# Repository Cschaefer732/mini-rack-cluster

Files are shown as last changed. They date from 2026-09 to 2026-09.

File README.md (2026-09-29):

# mini-rack-cluster

A 10-inch mini rack that consolidates a 3-node home fleet — dev workstation
with dual GPUs, an AI inference server, and a general-purpose server host —
plus its network gear, into one enclosure.

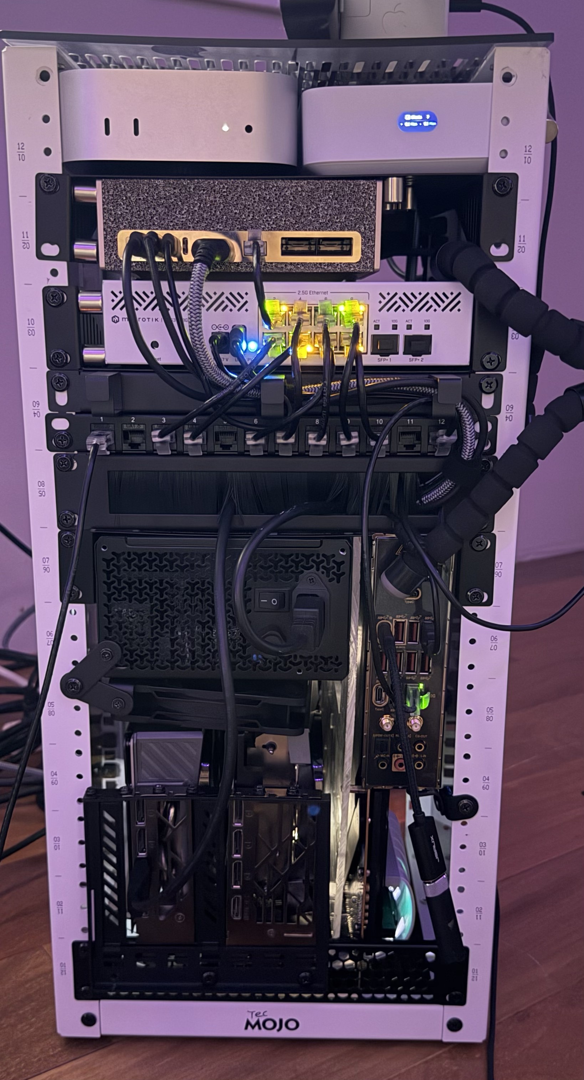
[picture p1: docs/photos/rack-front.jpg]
The rack, front view — Mac mini and UX7 gateway on top, riser card and MikroTik switch, patch panel and cable brush, PSU and vertically-mounted GPU/motherboard below


## Fleet

| Node | Role | Hardware |
|---|---|---|
| **nova-linux** | Dev workstation + GPU compute | MSI MEG X670E ACE (vertical-mounted on a hand-cut acrylic plate), Ryzen 9 9950X, RTX 5080 + RTX 4070 Ti, 32GB DDR5-4800, WD_BLACK SN850X 4TB + SN770 2TB NVMe |
| **machub** | General server host | Mac mini M4 (base, 16GB/256GB) — Vault, Postgres, IB/TWS, game streaming |
| **spark-a81e** | AI inference node | NVIDIA DGX Spark, GB10 Grace-Blackwell, 128GB unified memory — ollama model serving |
| — | Switch | MikroTik CRS310-8G+2S+ |
| — | Gateway/router | UniFi UX7 (UDMA69B) |

Each node kept its existing role from the wider fleet (see
[`personal-pc-config`](https://github.com/Cschaefer732/personal-pc-config) for full
per-machine config) — this project is the physical consolidation into one rack, not a
new cluster software stack.

## Build notes

- The MSI X670E ACE doesn't fit a standard 10" rack shelf full-size, so the board was
  pulled from its original case and mounted vertically on a cut acrylic open-frame
  plate to fit the rack footprint.
- PCIe 5.0 riser cables carry both GPUs off-board to clear rack depth (RGEEK x16
  double-reverse riser for one card, TRYX vertical-mount riser for the other).
- Cooling: ARCTIC Liquid Freezer III Pro 360 AIO on the 9950X, OwlTree PWM fan hub for
  case/rack fans.
- Power: Corsair RM850e (850W, fully modular) for the compute node.
- Cable management: Tecmojo 12-port Cat6 patch panel, GeeekPi horizontal cable manager,
  Tecmojo brush cable-entry panel, Cat6a patch cables throughout.
- Enclosure: Tecmojo 12U 10" network rack, 10.23" deep.

## Parts list + pricing

Two columns: what was actually paid (or, for parts reused from the prior nova-linux
build, the original MSRP — no receipt on hand), vs. current market price as of
2026-09-26.

| Component | Price Paid / Original | Market Price Now |
|---|---|---|
| NVIDIA DGX Spark (GB10, 128GB unified) | $4,800 | $4,699 (NVIDIA FE) — OEM partner street price ranges $4,100–$7,900 |
| MSI GeForce RTX 5080 Gaming Trio | $1,400 | ~$1,199–$1,800 (avg ~$1,580) |
| Apple Mac mini M4 (16GB/256GB) | $500 | ~$700–$1,050 — discontinued May 2026, resale now above launch price |
| MSI MEG X670E ACE motherboard | $699.99 (MSRP, reused part — no receipt) | $799.99 |
| AMD Ryzen 9 9950X | $649 (MSRP, reused part) | ~$499.99 |
| MSI GeForce RTX 4070 Ti Gaming Trio | ~$874 (MSRP, reused part) | ~$809.99 |
| WD_BLACK SN850X 4TB NVMe | $699 (MSRP, reused part) | ~$639.99 (volatile, seen $270–$640) |
| WD_BLACK SN770 2TB NVMe | $269.99 (MSRP, reused part) | ~$400 (NAND shortage) |
| Crucial 32GB DDR5-4800 (CT32G48C40U5) | ~$110 (est., no clean launch record) | ~$268–$538 (DRAM shortage) |
| MikroTik CRS310-8G+2S+ switch | $208.80 | $208.80 |
| UniFi UX7 gateway | $234 | $199 |
| Tecmojo 12U 10" rack enclosure | $139.90 | $139.90 |
| Corsair RM850e 850W PSU | $115.99 | $115.99 |
| TRYX PCIe 5.0 vertical riser | ~$74.99 | $74.99 |
| ARCTIC Liquid Freezer III Pro 360 AIO | ~$74.99 | $69.89 |
| RGEEK PCIe 5.0 x16 double-reverse riser | $39.99 | $39.99 |
| DIY acrylic open-frame case (cut for vertical mobo mount) | $29.89 | $29.89 |
| Tecmojo 12-port Cat6 patch panel | $15.99 | $15.99 |
| Tecmojo brush cable-entry panel | $14.69 | $14.69 |
| OwlTree 4-pin PWM fan controller | $16.99 | $16.99 |
| GeeekPi 10" horizontal cable manager | $11.19 | $11.19 |
| Cat6a patch cables (10-pack) | $10.99 | $10.99 |
| **Total** | **~$10,990** | **~$11,519** |

Build cost went *up* since assembly — the 2026 AI-driven GPU/NAND/DRAM shortage
outpaced normal depreciation on every reused part.

## Repo layout

```
docs/           build write-ups, LinkedIn post draft, photos
configs/        network device summaries (port maps, gateway notes — no raw exports)
cad/            slide-out mobo/GPU/PSU tray: tray-v1/ (current, from asset-forge/3d-design) + OpenSCAD v0.1-0.6 history
scripts/        automation — TODO, none written yet
wiki/           Obsidian-compatible knowledge layer for this project
```

## Status

- [x] Physical build complete
- [x] Parts + pricing documented
- [x] Build photos added (`docs/photos/`)
- [ ] Slide-out mobo/GPU/PSU tray — v1.0 rebuilt from zero in `cad/tray-v1/` (edge-on board, 10-inch 8U faceplate, 280 audit checks pass, 9 sabotage mutants caught); needs a measured rack opening, slide hardware, and a dry fit before printing
- [ ] Rack elevation / wiring diagram
- [ ] `scripts/` — no automation defined yet

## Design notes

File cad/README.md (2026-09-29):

> **SUPERSEDED 2026-09-29.** Everything below is the OpenSCAD v0.1-0.6 history. Those versions
> modelled the motherboard as a plate facing the front; it stands edge-on with its IO edge to the
> front (measured from the build photo). The current design is [`tray-v1/`](tray-v1/README.md),
> built and audited from [`asset-forge/3d-design`](https://github.com/Cschaefer732/asset-forge/tree/main/3d-design).
> Also wrong in the files below: the EIA-310 hole pattern, the board dimensions (304.8 mm is the
> IO edge), and the ATX hole table.

# CAD — mobo/GPU/PSU slide-out tray

`mobo-gpu-psu-tray.scad` — parametric OpenSCAD model. Every dimension that
matters is a named variable at the top of the file with a comment saying
whether it's a sourced spec or a placeholder you need to verify.

**Status: v0.6 draft, not print-ready, and now honestly blocked on one
real measurement.** Manifold STLs export clean (`NoError` on the combined
model and all per-part exports). Every panel's cutout is now checked to
actually fit inside the panel it's cut from. But the floorplan this
round surfaced a real physical conflict: **the PSU and IO shield, sized
to what they actually need, require ~341mm side by side — the rack is
only ~270-280mm.** See "v0.6" below before printing anything.

## v0.6 — floorplan rebuilt from real sizes, found a real width conflict

v0.5 shipped with two more defects, on top of the ones it claimed to
fix:

- **The IO rotation in v0.5 was wrong.** It was based on the photo
  showing ports "stacked vertically" and concluding the whole board was
  mounted rotated 90&deg;. Cropped and zoomed into the actual photo this
  round: that's just the MSI X670E ACE's completely standard rear IO
  panel — a 2-row USB grid, side-by-side WiFi antennas, a row of audio
  jacks. Totally normal, unrotated layout. Worse, the v0.5 fix only
  rotated the *cutout* and left the *standoff hole pattern* on the old
  unrotated mapping — even if the board really had been rotated, holes
  and cutout are rigidly on the same PCB and can't be rotated
  independently. Reverted to the standard orientation.
- **The PSU cutout (150mm) was being cut from a panel sized to
  `half_width` (130mm)** — narrower than the cutout itself. Same class
  of bug as the v0.4 IO overflow, just never caught because nobody
  checked the numbers against the panel bounds, only glanced at a
  render. Both the PSU (150mm) and the IO shield (158.75mm) need more
  than half of any width this tray plausibly has — the "split into two
  equal half-columns" floorplan never actually fit either real
  component, all the way back to when it was introduced.

Fix: columns are now sized bottom-up from each component's real
footprint (`psu_col_w`, `io_col_w`) instead of an assumed 50/50 split,
and both cutouts are re-verified to sit fully inside their own panel
(checked by rendering each part alone and looking, not just the combined
assembly).

That surfaced the real problem: `psu_col_w + spine_width + io_col_w` =
**340.75mm**, computed from real, mostly-sourced dimensions — but
`rack_clear_width` (270mm) is itself only a reasoned placeholder. The
model now makes this conflict visible instead of hiding it:
`rack_reference()` still draws its posts at the assumed 270mm, while the
tray itself is sized to whatever it actually needs
(`tray_width = max(rack_clear_width, required_tray_width)`) — so in the
`fit_check` render, the tray now visibly overhangs the rack posts on the
right side. That gap is real information, not a rendering bug: **either
the real rack is wider than 270mm, or the PSU and motherboard don't
actually sit fully side-by-side at the same depth in the real build (the
photo could be foreshortening an overlap that isn't there in plan view),
or the layout needs to change from side-by-side to stacked.** This can't
be resolved with more reasoning from a photo — it needs the actual rack
interior width measured, and ideally a straight-on plan-view photo (not
the current angled 3/4 shot) to check whether the PSU and IO shield
really share the same depth plane.

## v0.5 — IO orientation fixed, real flanges, real GPU mount

v0.4 still had three real defects, caught by re-checking the actual
render (not just trusting the code) against the photo:

- **IO cutout was 90&deg; wrong.** v0.4 cut it in the desktop-case
  orientation (158.75mm wide, 44.45mm tall) — but this build mounts the
  board rotated 90&deg;, and `docs/photos/rack-front.jpg` clearly shows
  the USB/audio/network ports stacked top-to-bottom, not side by side.
  Worse, at 158.75mm wide the old cutout didn't even fit inside the
  130mm-wide bezel column — it would've overflowed sideways. Now the cut
  is 44.45mm wide × 158.75mm tall, and the bezel column has its own
  height (independent of the PSU row) sized to fit it.
- **Rack ears were floating posts, not bonded flanges.** The v0.4 ear
  touched the base plate along a single zero-area edge — geometrically
  it exported as one manifold, but it's not a real load-bearing joint.
  Rewrote `rack_ear()` as a proper L-bracket: a vertical leg (holes,
  faces the rack rail) plus a horizontal foot that overlaps the tray's
  edge for the ear's *full height*, so there's real volumetric contact.
  Also: the `fit_check` render now lifts the tray to `rack_rail_end_offset`
  so the ears' holes visually line up with the rack reference frame's
  holes — v0.4 had the tray sitting at the rack's absolute floor (Z=0),
  33mm below the first real U, which made the flanges look disconnected
  from the rack's actual hole line even though the print geometry itself
  was fine (U-pitch is periodic, so it lines up once actually installed —
  but the *visualization* was misleading).
- **GPU brackets had nothing to actually mount a card to.** v0.4's fins
  had 4 guessed holes with no real spacing/size rationale and no
  structure bearing the card's weight — just two open fins. Added a real
  support shelf (`gpu_shelf_depth`) each card's PCB rests on, plus one
  bracket screw hole per fin sized from a real source: Protocase's
  ATX/PCI enclosure design guide gives 2.71mm (0.1065in) as the 6-32 tap
  drill size for a PCI bracket screw hole, and separately confirms the
  20.32mm PCI slot pitch already in this file (`slot_pitch`). Hole is
  sized up to 3.5mm clearance since this prints in plastic (screw + nut
  or heat-set insert, not tapped directly). Shelf/hole *position* is
  still a placeholder pending dry-fit — the source only gives real sizes,
  not this custom riser-mounted layout's positions.

## v0.4 — real mounting holes, rack reference frame, layout fixed from the photo

- **Layout corrected against the actual build photo**
  (`docs/photos/rack-front.jpg`), not a guess: PSU top-left (open bracket,
  exposed face, no blanking panel — matches the photo), motherboard IO
  shield top-right, two GPUs full-width below as open brackets with
  coolers exposed and slot/connector end down, center spine, outer
  mounting flanges. Everything before this was wrong — PSU was in the
  wrong corner and the whole thing used solid blanked panels instead of
  open bracket/shelf mounting like the real build.
- **Real PSU screw holes.** Sourced from Intel ATX Spec 2.01, Fig. 9 — the
  actual 4-hole pattern (asymmetric, not a rectangle) for a standard
  150×86mm ATX PSU rear face. High confidence — this is a genuinely
  universal spec.
- **Adapted motherboard standoff holes.** Sourced the real standard-ATX
  9-hole table from the same spec, Fig. 3 — but it's for a 305×244mm
  board, and the X670E ACE is 277×304.8mm. Applying the coordinates
  unscaled would put 3 of 9 holes off the board's edge. X is scaled by
  277/305; Y is left unscaled (EATX boards conventionally keep the
  standard hole positions near the IO edge and add length below rather
  than stretching everything). Cut as small slots, not tight holes, for
  adaptation tolerance. **Not verified against MSI's actual drawing —
  cross-check against the existing acrylic plate before drilling.**
- **Rack reference frame** (`render_part="rack_reference"`), modeled at
  the Tecmojo 12U 10in rack's real sourced dimensions (280×260×635.8mm,
  44.45mm U-pitch, 33mm rail end offset) so the tray's fit can be checked
  visually, not just assumed. Not a printable part.
- **`rack_clear_width` reasoning changed.** The research pass found an
  uncaptioned 210mm figure on the manufacturer's diagram, explicitly
  flagged as uncertain — and it contradicts the photo (a 277mm board is
  visibly mounted). Using 270mm instead (overall width minus an assumed
  rail-wall thickness). Still a placeholder either way.
- **Caught and fixed a real geometry bug during this pass**: the first
  draft sized the motherboard's visible panel to `half_width` (130mm) and
  positioned the real 9-hole pattern relative to that column — but the
  board is 277mm wide, so most holes computed to X positions outside the
  visible panel entirely. Fixed by splitting the motherboard into two
  pieces: a narrow front-facing IO bezel (matches what's actually visible
  in the photo) and a separate full-board-width standoff plate set back
  in depth (runs behind both the PSU and IO columns, which is physically
  necessary since the real board is wider than either column alone).

## Before printing

0. **Blocking: measure the real rack interior width and resolve the
   341mm-vs-270mm conflict** (see v0.6 above). Everything else in this
   list assumes a side-by-side PSU+mobo layout that may not survive that
   measurement.
1. **Measure `rack_clear_width`.** Currently 270mm, reasoned from overall
   width minus assumed wall thickness — not measured, and known to be
   too narrow for what the layout currently needs (see item 0).
2. **Cross-check the adapted motherboard holes** against the existing
   acrylic plate. They're derived from a real spec but scaled for a
   different board size than the source table covers.
3. **Verify the IO cutout position** — size (158.75×44.45mm, standard
   unrotated orientation) is a real universal standard; its position
   within the bezel column is still a placeholder.
4. **Verify the PSU holes** land correctly relative to your specific
   RM850e — the 4-hole ATX pattern is genuinely universal, but confirm
   `psu_d` (140mm, estimated) against the real unit too.
5. **Source the 4070 Ti's real dimensions** — the GPU segment still uses
   the 5080's numbers (338×140×50mm) for both cutouts.
6. **Dry-fit the GPU bracket** shelf position and screw hole height —
   the shelf/hole *sizes* are sourced (see below), their *position*
   along the tray depth and row height is still a placeholder fixture,
   not measured against real riser routing.
7. **Confirm slide hardware and `slide_hole_pitch`.**
8. **Resolve the 8U vs. ~384mm gap** (see below) before committing to ear
   height.

## Sourced (trustworthy) vs. placeholder (verify) dimensions

| Variable | Value | Confidence |
|---|---|---|
| `board_w` / `board_d` | 277 × 304.8mm | Sourced — MSI/Micro Center |
| `u_pitch` | 44.45mm | Sourced — matches this rack's mfr spec + EIA-310 |
| `rack_overall_w/d/h`, `rack_rail_end_offset` | 280×260×635.8mm, 33mm | Sourced — Tecmojo mfr spec |
| `atx_holes_in` (9-hole mobo pattern) | see table in .scad | Sourced (Intel ATX 2.01 Fig. 3) for a 305×244mm board — **adapted**, not verified, for this 277×304.8mm board |
| `psu_holes` (4-hole PSU pattern) | see table in .scad | Sourced (Intel ATX 2.01 Fig. 9) — genuinely universal, high confidence |
| `io_w` / `io_h` | 158.75 × 44.45mm | Sourced — standard ATX/EATX IO shield opening |
| `gpu_card_length/height/thickness` | 338 × 140 × 50mm | Sourced for the **5080 only** — 4070 Ti reuses these as a placeholder |
| `slot_pitch` | 20.32mm | Sourced — Protocase ATX/PCI enclosure design guide, Fig. 9 |
| `gpu_bracket_hole_d` | 3.5mm | Sourced size (Protocase: 2.71mm/0.1065in 6-32 tap), sized up for a plastic clearance hole — **position still a placeholder** |
| `rack_clear_width` | 270mm | **Placeholder — measure yours**; the layout as sized needs 340.75mm (`required_tray_width`), 70mm more than this — blocking, see v0.6 above |
| `psu_col_w` / `io_col_w` | 156mm / 174.75mm | Derived from real sourced PSU/IO sizes + margin — replaces the old `half_width` 50/50 split, which fit neither |
| `psu_d` | 140mm | Estimate — verify against RM850e |
| `tray_u_height` (requested) vs. `actual_panel_height` (used) | 8U (355.6mm) vs. ~355.6mm now (PSU/IO row height dropped once decoupled from the GPU row) | Recompute if row proportions change |
| `hole_a`/`hole_b`/`hole_c` (EIA-310 intra-U spacing) | 6.35/15.875/25.4mm | Standard convention — not explicitly confirmed for this specific rack SKU (inferred from its 10-32 tapped + cage-nut hardware kit) |
| `mount_plate_depth` | 12mm | Placeholder |
| `slide_hole_pitch` | 32mm | Placeholder |

## Render / export

```
openscad --render -o preview-top.png --imgsize=1800,1300 --autocenter --viewall \
  --projection=ortho --colorscheme=Tomorrow mobo-gpu-psu-tray.scad

# Combined printable model (excludes the rack reference frame)
openscad -o mobo-gpu-psu-tray.stl mobo-gpu-psu-tray.scad

# Per-subsystem parts, plus the non-printable rack reference frame
for part in structural mobo gpu psu rack_reference; do
  openscad -D "render_part=\"$part\"" -o "part-$part.stl" mobo-gpu-psu-tray.scad
done

# Combined view with the rack reference frame overlaid, for fit-checking only
openscad -D 'render_part="fit_check"' -o fit-check.png ...
```

Always pass `--render` for PNG preview exports — `openscad -o file.png`
without it uses preview mode, which can silently fail to display a real,
correctly-differenced cutout (bit the v0.1 IO cutout once already).

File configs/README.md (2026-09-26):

# Network configs

Configs for the two network devices physically in this rack. Full history,
troubleshooting notes, and the raw RouterOS export live in the fleet-wide
`personal-pc-config` repo (private) — this is a public repo, so only an
abstracted summary lives here. RouterOS exports don't carry passwords, but
they do carry the device serial number, hardware MAC, license/software ID,
and internal LAN topology, which have no reason to be public.

## MikroTik CRS310-8G+2S+ (switch)

Port map:

| port | device |
|---|---|
| ether2 | spark-a81e (DGX Spark) |
| ether3 | uplink to UX7 gateway |
| ether7 | macbook-pro (external to the rack) |
| ether8 | nova-linux |

## UX7 gateway (UniFi Express 7, UDMA69B)

Not exported here — UniFi OS config lives behind SSO + 2FA with no local export
file. Key applied settings, for reference:

- DHCP reservations pinned for spark, nova-linux, macbook-pro, and machub
- DHCP pool trimmed to avoid conflicting with the MikroTik's static management IP
- No WAN-facing admin access (UniFi default-deny, untouched)

Credentials and full detail: `personal-pc-config/network/ux7/README.md` (private repo).

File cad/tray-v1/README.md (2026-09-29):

# Slide-out tray v1.0

Rebuilt from zero on 2026-09-29. Source, spec and audit live in
[`asset-forge/3d-design/assets/rack-tray/`](https://github.com/Cschaefer732/asset-forge/tree/main/3d-design/assets/rack-tray);
this folder holds the published outputs. Supersedes the OpenSCAD v0.1-0.6 in the parent folder,
which modelled the motherboard facing the front instead of standing edge-on.

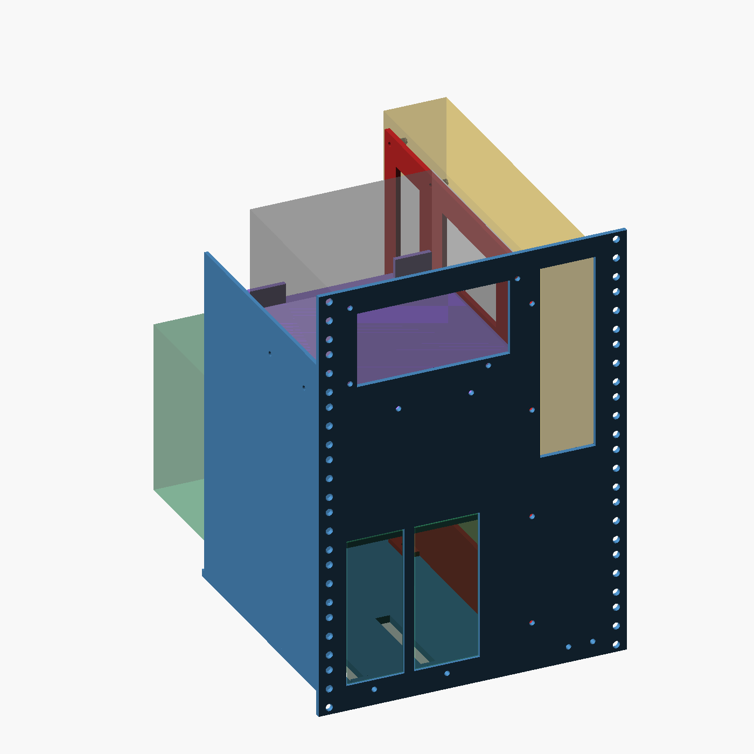
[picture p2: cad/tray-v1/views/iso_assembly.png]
assembly


## What it is

An 8U (354.8 mm) faceplate for a 10-inch rack with EIA-310 ear holes down both sides, and a
printed chassis behind it:

- **PSU** (top-left): rear face on the faceplate, four screw holes plus a window, resting on a shelf
  with a wall on its left and stops behind it.
- **Motherboard** (right): stands edge-on like in a PC tower, IO edge to the front, portrait IO
  window in the faceplate, a printed frame at X 156-160 mm carrying the ten ATX standoff holes.
  It hangs out the back.
- **GPUs** (bottom-left): PCIe fingers down, port brackets facing out through two windows, bracket
  tab screwed to a ledge behind the faceplate.
- Slide interface: eight placeholder holes in the base for under-mount slides.

| File | Part |
|---|---|
| `faceplate.stl/.step` | 254 x 354.8 x 12 mm |
| `base` | 222 x 236 x 20 mm |
| `left_wall` | 270 x 232 x 18 mm |
| `psu_shelf` (purple in the viewer) | 170 x 153 x 40 mm |
| `board_frame` (red in the viewer) | 331 x 248 x 32 mm |

All fit a 360 mm bed. `report.json` is the audit output (280 checks, exit 0).

## How it was checked

Numbers, not renders: watertight and single-body, bounds, an independent volume balance, probes that
test both the hole and the material around it, interference / clearance / contact between parts and
reference bodies for the PSU, board and cards, rack-opening envelope, print-bed fit. Nine
deliberate sabotages of the builder (rotated window, mirrored holes, shifted hole, swapped axes,
missing hole, cutter that misses...) each fail the real spec. See
`asset-forge/3d-design/README.md`.

## Before printing (full list in the asset README)

1. Measure the rack opening: 222.25 mm is assumed and the layout uses all of it.
2. Side-mount slides do not fit (they need 25 mm); pick under-mount slides and replace the base holes.
3. Confirm PSU depth (160 mm assumed) and the PSU screw pattern's handedness, the 4070 Ti size
   (337 x 140 x 56 assumed), and the 50 mm of component height allowed above the PCB.
4. Dry-fit the GPU ledge: the cooler shroud is assumed to start 10 mm behind it.
5. The GPU ledge bridges the two GPU windows when the faceplate is printed face-down. Use supports.
6. No strength analysis yet: ribs may be needed under the PSU shelf and behind the board frame.

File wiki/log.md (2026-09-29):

# Log

## [2026-09-26] ingest | Fleet Nodes
Sourced from personal-pc-config wiki entities (nova-linux, machub, spark-a81e)
plus live SSH hardware query on nova-win for exact NVMe/RAM models.

## [2026-09-26] ingest | Network Gear
Sourced from personal-pc-config/network (UX7, MikroTik CRS310).

## [2026-09-26] ingest | Pricing
Sourced from user-provided Amazon order screenshots, user-confirmed paid
prices, and web research for MSRP/current market on major components.

## [2026-09-26] ingest | LinkedIn Post
Draft written to docs/LINKEDIN_POST.md, technical-showcase angle per user choice.

## [2026-09-26] ingest | Slide-out Tray CAD
v0.1 parametric OpenSCAD model drafted: mobo (offset right), GPU bracket
fin, PSU cradle, front rack ears, slide-rail mounting tabs. Caught and
fixed an ear-orientation bug during first render. Flagged rack_clear_width
and motherboard standoff holes as needing real measurement before print.

## [2026-09-26] ingest | Slide-out Tray CAD v0.2
Switched motherboard mount from flat/horizontal to vertical after the IO
shield needed to be front-facing (matches the current acrylic-plate
build's orientation). Added ATX-standard IO cutout (158.75x44.45mm),
raised tray_u_height 6->8, color-coded 4 subsystems (structural/mobo/
gpu/psu), exported per-part STLs. Caught and documented a --render vs
preview-mode PNG export pitfall that hid a real, correctly-cut IO
cutout from the v0.1 preview image (STL export was trustworthy the
whole time).

## [2026-09-26] ingest | Slide-out Tray CAD v0.3
Rebuilt around a "rear panel" model per front-panel layout description:
PSU top-right, GPUs stacked below (sized from RTX 5080's real 338x140x50mm,
4070 Ti unsourced/reused placeholder), mobo + spine in remaining column,
mounting flanges confirmed. Found real PSU+2GPU stack needs ~384mm vs
requested 8U (355.6mm) - flagged rather than silently shrinking sourced
dimensions. Fixed a leftover nonsense algebra bug in the GPU cutout width
expression caught during review before export.

## [2026-09-26] ingest | Slide-out Tray CAD v0.4
Corrected layout against docs/photos/rack-front.jpg after v0.3's guessed
arrangement was wrong (PSU top-right vs actual top-left, solid blanked
panels vs actual open bracket/shelf mounting). Sourced real Intel ATX
Spec 2.01 mounting hole tables: PSU 4-hole pattern (genuinely universal,
implemented directly) and motherboard 9-hole pattern (for a 305x244mm
board, adapted/scaled for the X670E ACE's 277x304.8mm size - not
verified against MSI's own drawing). Added a rack reference frame
modeled at the Tecmojo 12U rack's real sourced dimensions. Caught and
fixed a bug where the mobo panel was sized to a 130mm half-column but
the holes were computed for the real 277mm board, landing most holes
outside the visible panel - split into a front IO bezel + full-width
standoff plate set back in depth.

## [2026-09-28] ingest | Slide-out Tray CAD v0.5
Called out for three defects still present in v0.4's actual render, not
caught before shipping it. (1) IO cutout was cut in desktop-case
orientation (158.75mm wide) and didn't fit its own 130mm bezel column -
re-checked the photo, ports stack vertically, rotated the cutout 90deg
and gave the bezel its own column height. (2) Rack ears touched the base
plate along a single zero-area edge, not a real bonded joint - rebuilt
rack_ear() as an L-bracket with a foot overlapping the tray's full
height, and fixed the fit_check render sitting 33mm below the rack's
real first U (rack_rail_end_offset), which made the flanges look
disconnected from the rack's hole line in the visualization even though
the print geometry itself was periodic-correct. (3) GPU brackets had no
real mounting structure - added a support shelf the card's PCB rests on
plus a bracket screw hole sized from Protocase's ATX/PCI enclosure
design guide (2.71mm/0.1065in 6-32 tap, sized up to 3.5mm clearance for
plastic), which also independently confirmed the 20.32mm slot_pitch
already in the file. Re-exported all STLs (still NoError/manifold),
republished the viewer (v6).

## [2026-09-28] ingest | Slide-out Tray CAD v0.6
User: "you need to fucking scrap the design you made, its fucking
dogshit." Asked scope via clarifying question - user chose keep the
goal, restart the design from zero. Before rebuilding, re-checked the
v0.5 IO rotation against a zoomed crop of the real photo: it's a
completely standard MSI X670E ACE rear IO panel (2-row USB grid,
side-by-side WiFi antennas, audio row) - not rotated. v0.5's "fix" was
based on misreading normal port stacking as rotation evidence. Reverted.
Separately, re-checking every cutout against its own panel bounds (never
actually done before - only glanced at renders) found the PSU cutout
(150mm) was being cut from a 130mm-wide panel, same overflow class as
the IO bug, sitting undetected since v0.4. Root cause: the "two 130mm
half-columns" floorplan never fit either real component - not PSU
(150mm), not IO shield (158.75mm). Rebuilt column widths bottom-up from
real sourced sizes instead of an assumed 50/50 split. This surfaced a
real, previously-hidden conflict: psu_col_w + spine + io_col_w =
340.75mm, but rack_clear_width (the assumed rack interior width) is only
270mm - a 70mm gap. Made this visible instead of silently absorbing it:
rack_reference() still renders at the 270mm placeholder while the tray
sizes itself to what it actually needs, so fit_check now shows the tray
overhanging the rack posts. This is now the real blocker - needs an
actual rack measurement and a straight-on (not 3/4 angle) photo to
confirm PSU and mobo genuinely share one depth plane. Re-exported all
STLs (NoError/manifold), republished viewer (v7).

## [2026-09-29] ingest | Slide-out Tray v1.0 (rebuilt from zero)
Scrapped OpenSCAD v0.1-0.6. New design built in build123d in asset-forge/3d-design with a fail-closed
mesh audit: board edge-on (IO edge to the front, portrait IO window), 10-inch 8U faceplate with
corrected EIA-310 holes, ATX hole table re-read from the drawing, board axes corrected. 280 checks
pass; 9 builder-sabotage mutants fail the real spec. Outputs in cad/tray-v1/. Open: rack opening,
slide hardware, PSU depth and screw chirality, GPU B dimensions, dry fit. The 341 mm width
conflict recorded under v0.6 was caused by the wrong 3D reading and no longer applies.

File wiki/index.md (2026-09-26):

# Index

## Entities
- [Rack Enclosure](entities/rack-enclosure.md) — Tecmojo 12U 10" rack housing the fleet
- [Fleet Nodes](entities/fleet-nodes.md) — nova-linux, machub, spark-a81e specs + roles
- [Network Gear](entities/network-gear.md) — MikroTik switch + UX7 gateway

## Topics
- [Pricing](topics/pricing.md) — paid/MSRP vs current market, the appreciation finding
- [LinkedIn Post](topics/linkedin-post.md) — post draft status + open blockers
- [Slide-out Tray](topics/slide-out-tray.md) — v0.1 CAD draft, sourced vs. placeholder dimensions

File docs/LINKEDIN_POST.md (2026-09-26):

# LinkedIn post draft — technical build showcase

<!-- Angle: technical build showcase. Edit freely before posting. -->

I condensed my entire home compute fleet into a 10-inch rack.

Three nodes, one enclosure:
- **Dev workstation** — Ryzen 9 9950X, RTX 5080 + RTX 4070 Ti, MSI X670E ACE
- **AI inference server** — NVIDIA DGX Spark, GB10 Grace-Blackwell, 128GB unified memory
- **General server host** — Mac mini M4, running Vault, Postgres, and IB/TWS

Plus a MikroTik CRS310-8G+2S+ switch and a UniFi UX7 gateway, patched and cable-managed
inside the same 10" footprint.

The fun part: the X670E board doesn't fit a standard 10" rack shelf at full size. I pulled
it from its case and hand-cut an acrylic open-frame plate to mount it vertically — both
GPUs run off PCIe 5.0 riser cables to clear the rack depth.

The number that surprised me: I tracked what I originally paid against today's market
price for every part. Built for ~$11K — and thanks to the GPU/NAND/DRAM shortage running
through 2026, it would cost *more* to build today than it did when I built it. Every
component I reused from an older build (motherboard, CPU, both NVMe drives, RAM) is worth
more now than its original price.

Full parts list, pricing breakdown, and build notes: [repo link]

#homelab #selfhosted #AI #hardware

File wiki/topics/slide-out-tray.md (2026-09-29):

---
type: topic
updated: 2026-09-29
sources: [cad/tray-v1/README.md, cad/tray-v1/report.json, docs/photos/rack-front.jpg]
---

# Slide-out Mobo/GPU/PSU Tray

**Current: v1.0, rebuilt from zero** (`cad/tray-v1/`; source and audit in `asset-forge/3d-design/assets/rack-tray/`).
An 8U, 10-inch faceplate with corrected EIA-310 ear holes and a printed chassis behind it. The
board stands edge-on like in a PC tower: IO edge to the front, portrait IO window, a printed frame
carrying the ten ATX standoff holes, hanging out the back. PSU top-left on a shelf with four
screw holes and a window; two GPUs bottom-left, fingers down, bracket ports through windows, tab
screws to a ledge. 280 numeric checks pass, nine deliberate sabotages of the builder are each
caught. Still needs: a measured rack opening (222.25 mm assumed), slide hardware, PSU depth and
screw-pattern handedness, GPU B dimensions, a dry fit. See [[fleet-nodes]] for the components.

The OpenSCAD v0.1-0.6 below are kept as history only.

## History

- v0.1: flat/horizontal motherboard mount.
- v0.2: switched to vertical mounting, added the IO cutout.
- v0.3: reframed as a case rear-panel layout — but guessed the
  arrangement (PSU top-right, GPUs stacked under it, mobo full left
  column) instead of checking the photo. Wrong.
- v0.4: corrected against `docs/photos/rack-front.jpg` after being called
  out for not looking at it. Added real sourced mounting holes (PSU
  4-hole, mobo 9-hole adapted) and a rack reference frame. Caught a real
  bug mid-build: the motherboard's visible panel was sized to a 130mm
  half-column but the real board is 277mm wide, so most of the 9
  standoff holes computed to positions outside the panel. Fixed by
  splitting the motherboard into a narrow front-facing IO bezel (matches
  what's visible in the photo) and a full-board-width standoff plate set
  back in depth.
- v0.5: three more defects caught by actually re-rendering and looking,
  called out directly after v0.4 shipped with them still present. (1) IO
  cutout was cut in desktop-case orientation and didn't even fit its own
  column — rotated 90&deg; to match the photo's vertically-stacked ports.
  (2) Rack ears touched the base plate along a single zero-area edge —
  rebuilt as real L-brackets with a foot that bonds the full ear height,
  plus fixed the fit-check visualization sitting 33mm below the rack's
  real first U, which made the flanges look disconnected from the rack's
  hole line even though the print geometry was fine. (3) GPU brackets had
  no actual mounting structure — no shelf bearing the card's weight, no
  real screw spec. Added a support shelf plus a bracket screw hole sized
  from Protocase's ATX/PCI enclosure design guide (also independently
  confirms the 20.32mm slot pitch already in the file).
- v0.6: user called the whole design "dogshit" and asked for the mobo
  mount rebuilt from zero. Re-examining before rebuilding found the v0.5
  IO rotation was itself wrong — a zoomed crop of the photo shows a
  completely standard MSI ACE rear IO panel (2-row USB grid, side-by-side
  antennas), not a rotated one; reverted. Independently, re-checking
  panel-vs-cutout bounds (which nobody had actually done, just eyeballed
  renders) found the PSU cutout (150mm) was being cut from a 130mm-wide
  panel — same overflow bug as the IO cutout, never caught. Root cause:
  the "two 130mm half-columns" floorplan never fit either real
  component. Rebuilt column widths bottom-up from real part sizes
  (`psu_col_w`=156mm, `io_col_w`=174.75mm), which surfaced a genuine
  width conflict: side by side they need 340.75mm, and the rack's
  assumed clear width is only 270mm (itself unmeasured). Made this
  visible rather than hidden: `rack_reference()` still draws its posts
  at the 270mm placeholder while the tray is sized to what it actually
  needs, so the fit_check render now shows the tray overhanging the
  posts. Blocking on a real rack-width measurement and a straight-on
  plan-view photo to confirm the PSU and mobo really share one depth
  plane.

## [[fleet-nodes]] cross-reference

PSU: Corsair RM850e. Motherboard: MSI MEG X670E ACE (277×304.8mm — the
sourced standard-ATX hole table is for 305×244mm, hence the adaptation).
GPUs: RTX 5080 (real dims sourced) + RTX 4070 Ti (unsourced, reuses the
5080's numbers as a placeholder).

Full sourced-vs-placeholder table: `cad/README.md`.

## See Also

- [[fleet-nodes]]
- [[rack-enclosure]]
- v1.0 (2026-09-29): scrapped and rebuilt with a verification-first workflow after being told the
  design was wrong. Root cause of everything before: the photo was read, not measured. The IO strip
  in the photo measures ~59 x 152 mm next to a PSU face of known 150 x 86 mm, which puts the board
  edge-on with a portrait shield; every earlier version modelled a flat plate facing the front, so
  each "fix" (rotate the cutout, split the columns, add a spine) patched a wrong model. v0.6's
  341 mm-versus-270 mm "width conflict" was an artifact of that misreading. Also wrong before and
  fixed now: EIA-310 hole positions (6.35 / 22.225 / 38.1 mm, not 6.35 / 15.875 / 25.4), the board
  axes (304.8 mm is the IO edge, 277 the depth) so the scaled "adapted" ATX hole table was
  invalid, and the ATX hole table itself (10 holes, read from the Protocase drawing at 300 dpi).
  The new checker's first run caught two more of my mistakes before printing: two bolts landing in a
  lightening cut-out and a cutter nicking a plate by 1 mm.

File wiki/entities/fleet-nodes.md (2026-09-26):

---
type: entity
updated: 2026-09-26
sources: [personal-pc-config/wiki/entities, user-interview]
---

# Fleet Nodes

Three compute nodes physically consolidated into the [[rack-enclosure]]. Each
keeps its pre-existing fleet role — see `personal-pc-config` (private repo)
for full per-machine config and history.

## nova-linux — dev workstation + GPU compute

MSI MEG X670E ACE, Ryzen 9 9950X, RTX 5080 (primary) + RTX 4070 Ti (CUDA),
32GB DDR5-4800 single-channel (Crucial CT32G48C40U5), WD_BLACK SN850X 4TB +
SN770 2TB NVMe. Ubuntu 24.04.

The X670E ACE (EATX) doesn't fit a standard 10" shelf at full size — pulled
from its original case, mounted vertically on a hand-cut acrylic open-frame
plate. Both GPUs run off PCIe 5.0 riser cables to clear rack depth.

## machub — general server host

Mac mini M4, base config (16GB/256GB). Runs HashiCorp Vault, Postgres,
IB Gateway/TWS, plus game/desktop streaming (Parsec, Steam). Never sleeps.

## spark-a81e — AI inference node

NVIDIA DGX Spark, GB10 Grace-Blackwell superchip, 128GB unified LPDDR5X
memory (coherent CPU/GPU, no separate VRAM pool). Runs ollama (`:11434`) as
the fleet's model endpoint, plus the sea-wiki MCP and the ArchmediesSea agent
loop.

## See Also

- [[rack-enclosure]]
- [[network-gear]]
- [[pricing]]

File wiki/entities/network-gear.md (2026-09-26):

---
type: entity
updated: 2026-09-26
sources: [personal-pc-config/network, amazon-order-screenshots]
---

# Network Gear

Two devices, physically in the [[rack-enclosure]], carrying traffic for the
[[fleet-nodes]] plus macbook-pro (external to the rack).

## MikroTik CRS310-8G+2S+ (switch)

Port map: ether2 → spark-a81e, ether3 → uplink to UX7, ether7 → macbook-pro,
ether8 → nova-linux. Full config lives in the private `personal-pc-config`
repo — only the abstracted port map is public (`configs/README.md`); the raw
RouterOS export carries the device serial, hardware MAC, and internal LAN
topology, none of which belong in a public repo. Paid $208.80; current market
$208.80.

## UniFi UX7 (gateway/router, model UDMA69B)

DHCP reservations pinned per-device; no WAN-facing admin access. Paid $234;
current market $199 (Ubiquiti store, flat).

Cabling: Tecmojo 12-port Cat6 patch panel, GeeekPi horizontal cable manager,
Tecmojo brush cable-entry panel, Cat6a patch cables.

## See Also

- [[fleet-nodes]]
- [[rack-enclosure]]
- [[pricing]]

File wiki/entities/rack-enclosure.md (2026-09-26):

---
type: entity
updated: 2026-09-26
sources: [amazon-order-screenshots, user-interview]
---

# Rack Enclosure

Tecmojo 12U 10" network rack, 10.23" deep, 2 side translucent panels, 2 top
handles. Paid $139.90; current market $139.90 (flat, no drift observed).

Houses all three [[fleet-nodes]] plus the [[network-gear]].

## See Also

- [[fleet-nodes]]
- [[network-gear]]
- [[pricing]]

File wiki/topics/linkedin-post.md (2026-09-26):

---
type: topic
updated: 2026-09-26
sources: [docs/LINKEDIN_POST.md]
---

# LinkedIn Post

Draft lives at `docs/LINKEDIN_POST.md`. Angle: technical build showcase —
specs, the vertical-mount acrylic mod, and the [[pricing]] appreciation hook.
Blocked on real build photos and a decision on whether this repo goes public
(the post links to it).

## See Also

- [[pricing]]
- [[fleet-nodes]]

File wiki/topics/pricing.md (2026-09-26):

---
type: topic
updated: 2026-09-26
sources: [amazon-order-screenshots, user-interview, web-research]
---

# Pricing

Full table in the repo `README.md`. Two columns: price paid (or original MSRP
for parts reused from the prior nova-linux build, where no receipt survives),
and current market price as of 2026-09-26.

## Key finding

Total paid/original ≈ $10,990. Total market now ≈ $11,519. **The build is
worth more today than it cost to assemble** — every reused component
(motherboard, CPU, both NVMe drives, RAM) appreciated due to the 2026
GPU/NAND/DRAM shortage, outpacing normal hardware depreciation. This is the
headline for the [[linkedin-post]].

## Uncertain figures (flagged, not fabricated)

- RTX 4070 Ti Gaming Trio and X670E ACE / 9950X: no purchase receipt exists
  (reused from an earlier nova-linux build) — MSRP used as a stand-in.
- Crucial 32GB DDR5-4800 launch price: no clean historical record found;
  ~$110 is an estimate based on typical 2023 DDR5-4800 32GB pricing, not a
  sourced figure.
- TRYX riser vs. ARCTIC AIO: both showed $74.99 on the same purchase date in
  screenshots — user did not confirm which paid figure belongs to which item,
  so both are listed as ~$74.99.

## See Also

- [[fleet-nodes]]
- [[network-gear]]
- [[rack-enclosure]]

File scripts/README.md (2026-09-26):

# Scripts

No automation defined yet for this rack specifically — each node's own automation
(systemd units, keepalive scripts, etc.) stays in `personal-pc-config` under that
machine's folder. This directory is for scripts that are specific to the rack as
a physical/network unit (e.g. a fleet-wide health check hitting all three nodes).

Add scripts here as concrete needs come up — nothing speculative.

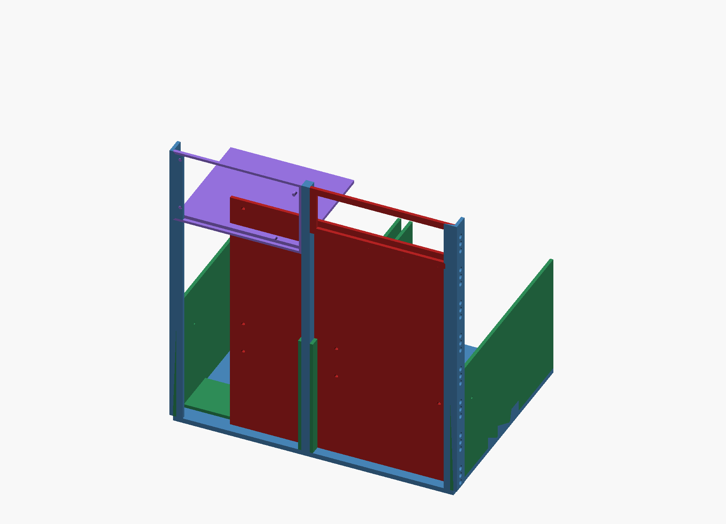
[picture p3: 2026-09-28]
cad/preview-top.png

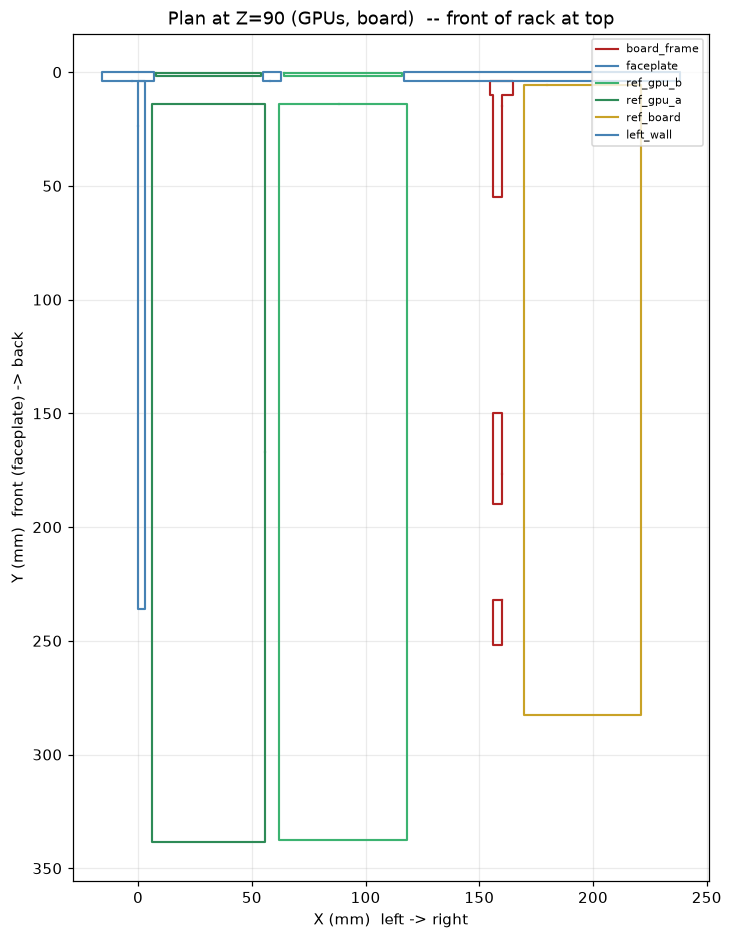
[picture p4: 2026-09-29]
cad/tray-v1/views/plan_z90_gpu_level.png

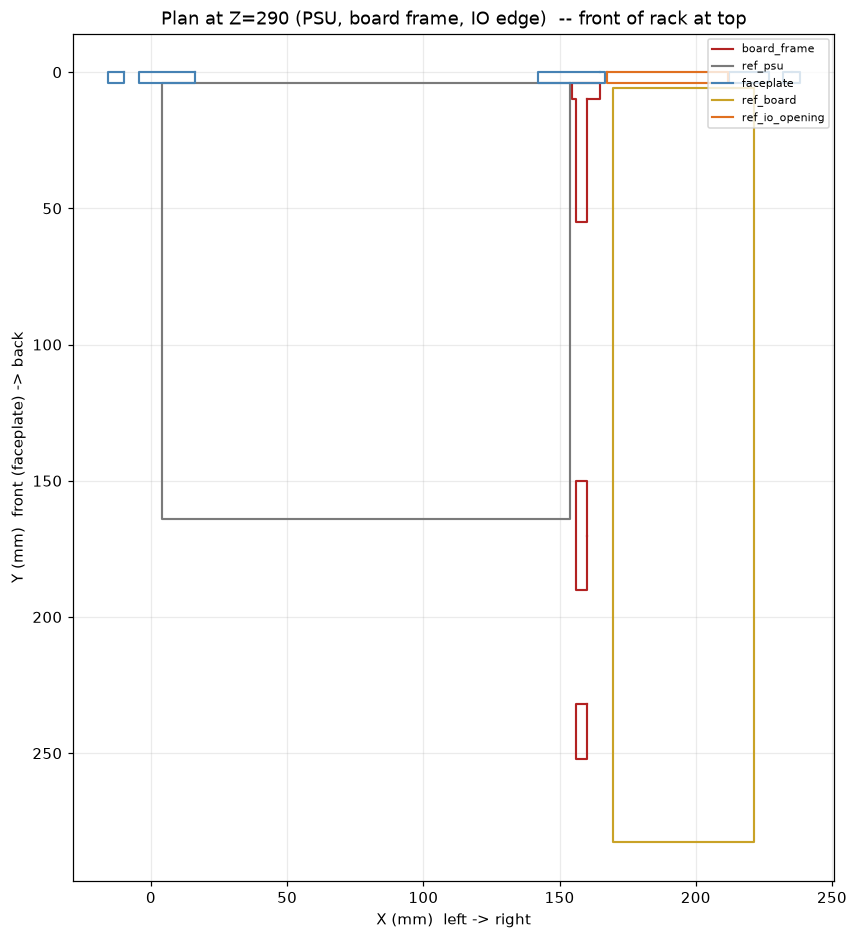
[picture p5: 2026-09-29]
cad/tray-v1/views/plan_z290_psu_level.png

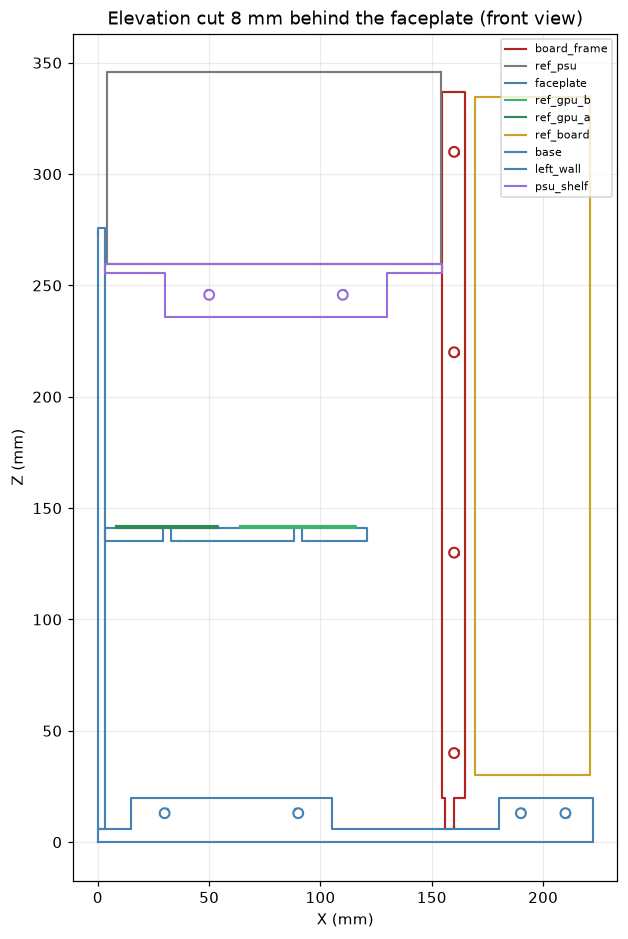
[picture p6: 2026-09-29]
cad/tray-v1/views/elev_y8_behind_faceplate.png

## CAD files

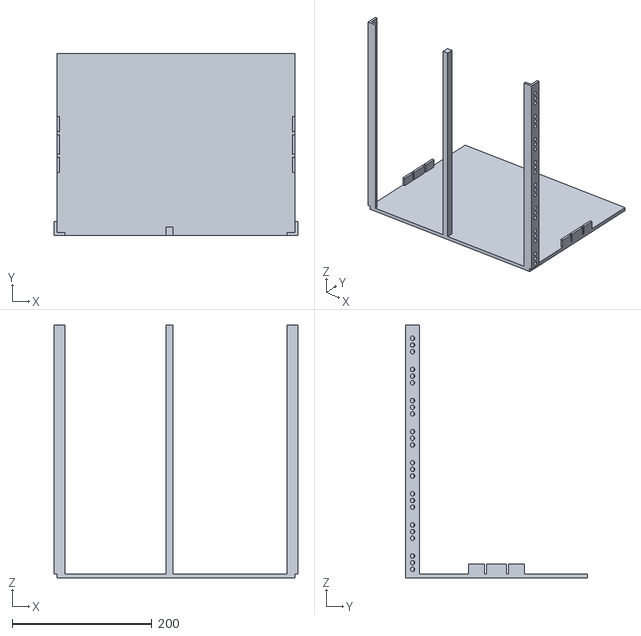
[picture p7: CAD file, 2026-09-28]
cad/part-structural.stl
348.8 x 260.0 x 361.6

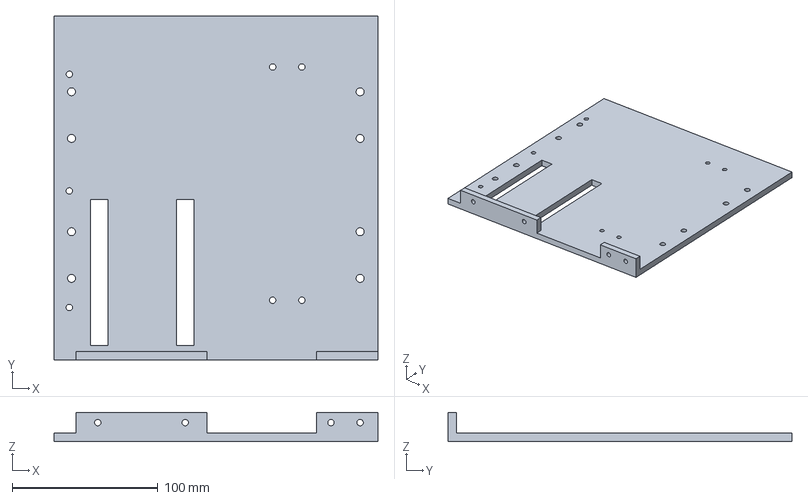
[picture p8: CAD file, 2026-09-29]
cad/tray-v1/base.step
222.2 x 236.0 x 20.0 mm

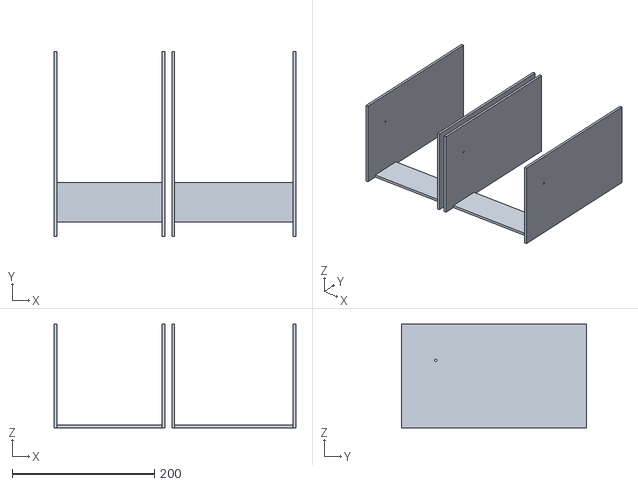
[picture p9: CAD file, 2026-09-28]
cad/part-gpu.stl
340.8 x 260.0 x 146.0

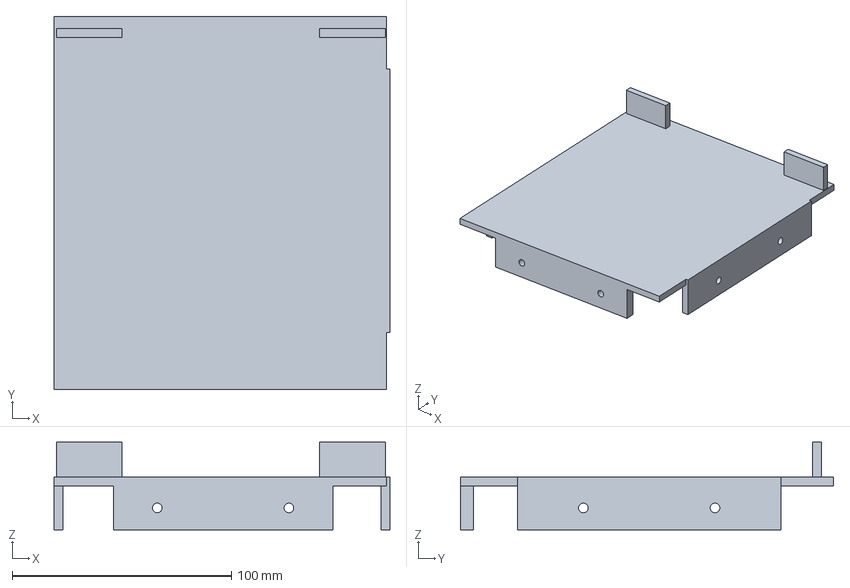
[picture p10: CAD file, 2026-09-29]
cad/tray-v1/psu_shelf.step
153.0 x 170.0 x 40.0 mm

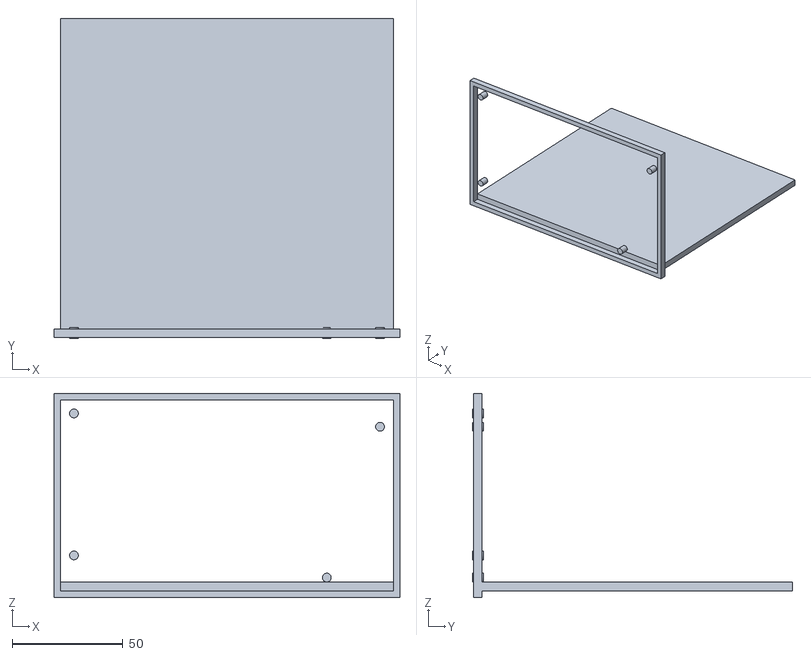
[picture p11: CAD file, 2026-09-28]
cad/part-psu.stl
156.0 x 144.5 x 92.0

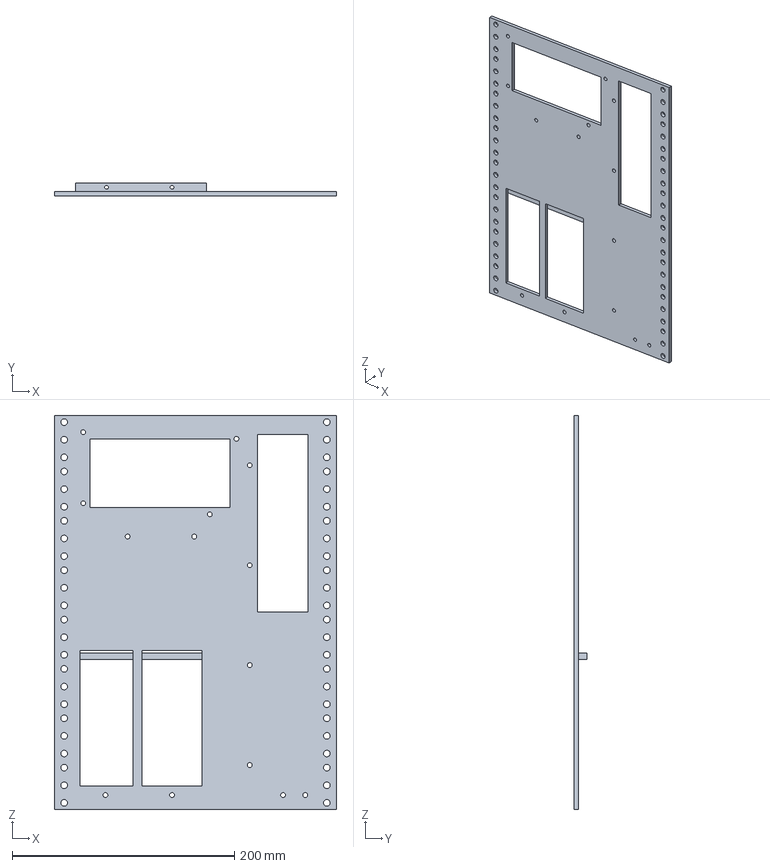
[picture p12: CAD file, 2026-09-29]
cad/tray-v1/faceplate.step
254.0 x 12.0 x 354.8 mm

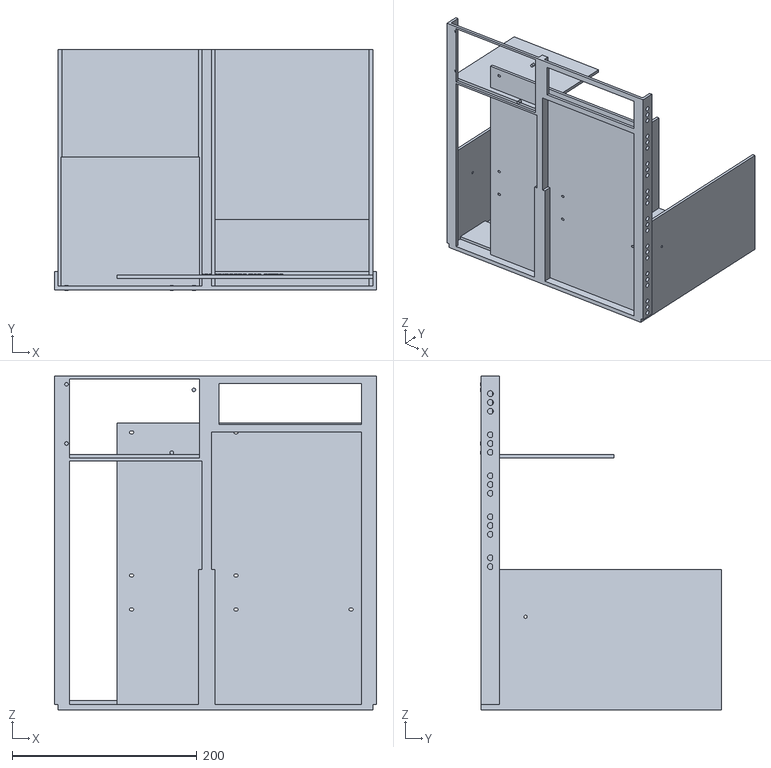
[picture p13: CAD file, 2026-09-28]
cad/mobo-gpu-psu-tray.stl
348.8 x 260.5 x 361.6

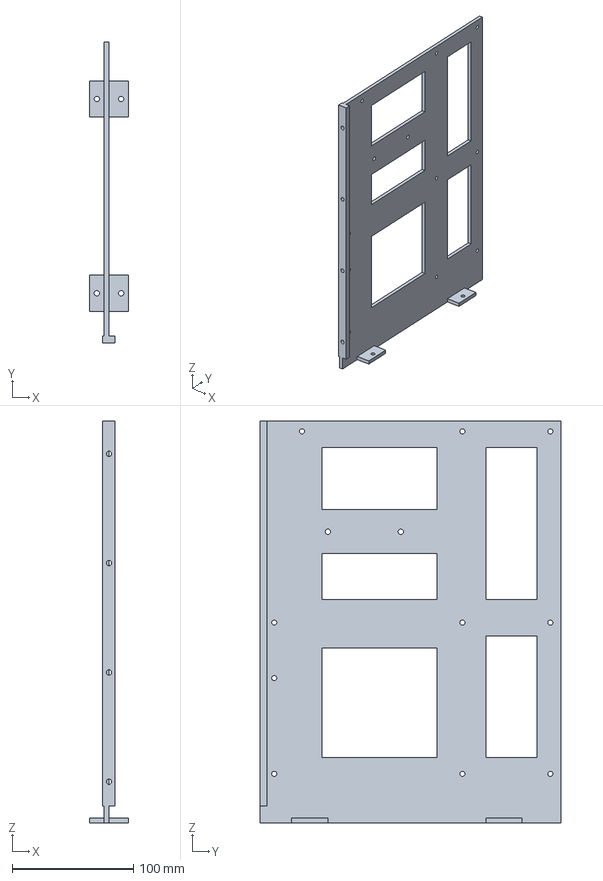
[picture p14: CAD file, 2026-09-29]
cad/tray-v1/board_frame.step
32.0 x 248.0 x 331.0 mm

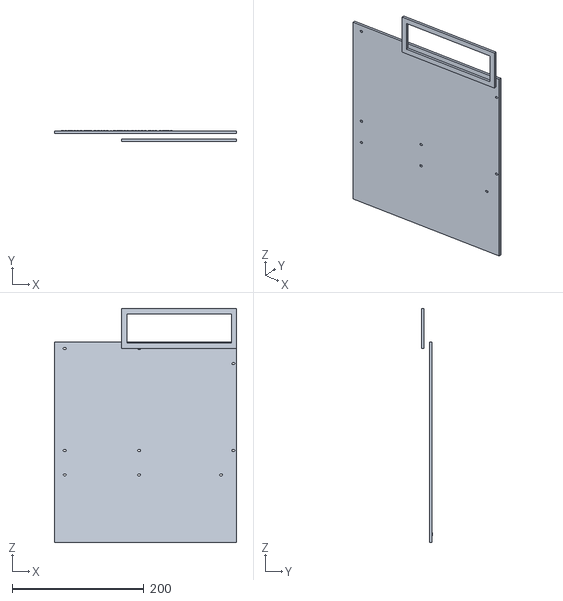
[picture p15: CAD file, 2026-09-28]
cad/part-mobo.stl
277.0 x 17.0 x 355.6

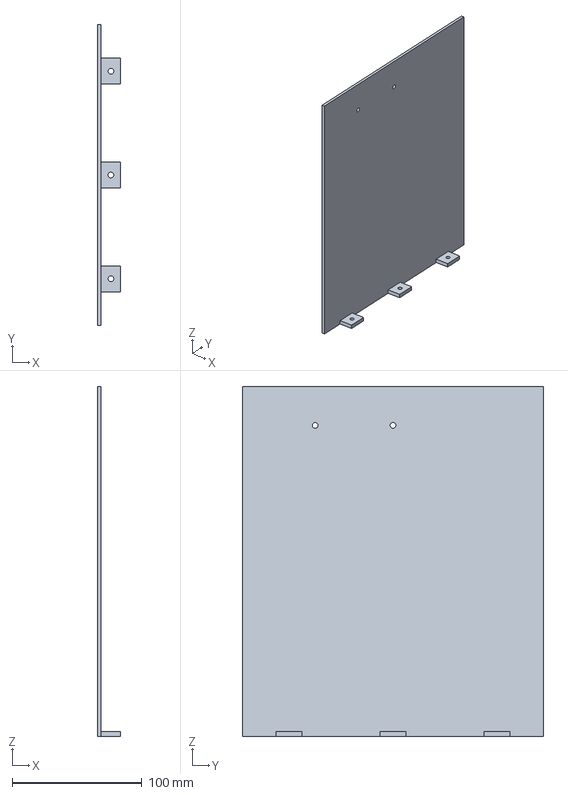
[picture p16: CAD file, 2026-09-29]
cad/tray-v1/left_wall.step
18.0 x 232.0 x 269.8 mm

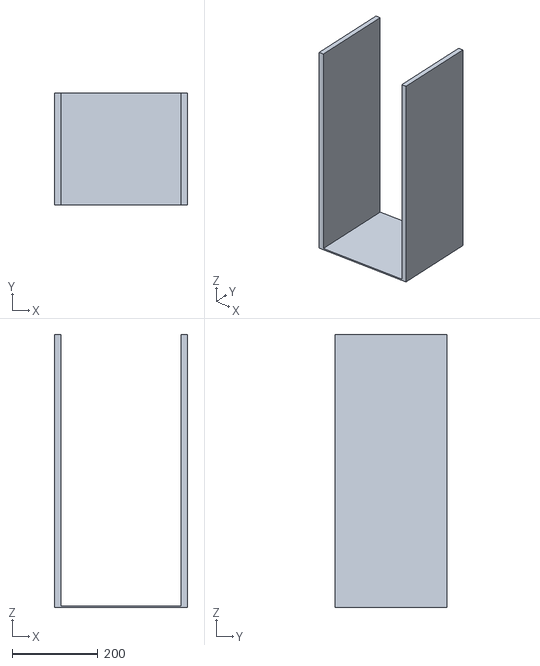
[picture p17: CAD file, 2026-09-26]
cad/part-rack_reference.stl
310.0 x 260.0 x 635.8

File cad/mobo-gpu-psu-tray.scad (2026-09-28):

// mobo-gpu-psu-tray.scad
//
// v0.6 — floorplan rebuilt from real component sizes after two rounds of
// overflow bugs were found by actually checking numbers against panel
// bounds instead of trusting a render glance:
//
//   1. The IO cutout was "fixed" in v0.5 by rotating it 90deg, on the
//      belief the board was mounted rotated (ports "stacked vertically"
//      in the photo). Zoomed into the actual photo this round: that's
//      just the MSI ACE's normal multi-row USB grid + side-by-side
//      antennas — completely standard, unrotated IO panel. The v0.5
//      rotation was based on a misread, not evidence. Reverted.
//   2. Separately, and independently of the IO cutout: the PSU cutout
//      (150mm) was being cut from a panel sized to `half_width` (130mm)
//      — wider than its own panel, same overflow class of bug as the IO
//      cutout, never caught because the render was never checked against
//      the actual numbers. Both PSU (150mm) and the IO shield (158.75mm)
//      need MORE than half of any width this tray plausibly has — the
//      "split into two equal half-columns" floorplan never fit either
//      real component. Replaced with columns sized to what each part
//      actually needs (psu_col_w, io_col_w below), computed bottom-up,
//      not assumed.
//
// Layout (matches docs/photos/rack-front.jpg):
//   top-left:     PSU, open bracket, exposed face, real ATX screw holes
//   top-right:    motherboard IO shield + standoff plate (full height —
//                 the board's own PCB runs behind/through the row below)
//   bottom, full width: 2 GPUs side by side, open brackets, coolers
//                 exposed, slot/connector end down
//   center spine + outer flanges tie it together and screw into the rack
//
// ============ VERIFY THESE BEFORE PRINTING — see cad/README.md ============

render_part = "all"; // "all" | "structural" | "mobo" | "gpu" | "psu" | "rack_reference"

// --- Rack — Tecmojo 12U 10in (ASIN B0F4JWMY4T), sourced from mfr spec ---
rack_overall_w       = 280;   // mm, sourced
rack_overall_d       = 260;   // mm, sourced (10.23in)
rack_overall_h       = 635.8; // mm, sourced (25.03in)
rack_u_count         = 12;
rack_rail_end_offset = 33;    // mm, sourced (1.3in, top/bottom to first usable U)
rack_clear_width     = 270;   // mm — REASONED, not sourced: mfr diagram had an
                                // uncaptioned 210mm figure the research agent flagged
                                // as uncertain. This is the ASSUMED real rack interior
                                // width — rack_reference() below draws its posts at
                                // exactly this number. If the tray's real required
                                // width (computed below from real part sizes) exceeds
                                // this, the fit_check render will show the tray poking
                                // outside the rack posts — that is deliberate: an honest
                                // fit conflict beats silently resizing the "rack" to
                                // match. MEASURE THE REAL ONE before printing.
u_pitch    = 44.45; // mm — EIA-310, sourced (matches this rack's mfr-stated U pitch)
hole_a     = 6.35;  // mm — EIA-310 intra-U hole positions. NOTE: confirmed as this
hole_b     = 15.875; // rack's convention only by inference (10-32 tapped + cage-nut
hole_c     = 25.4;  // kit strongly implies EIA-310, but not stated explicitly for this SKU)

tray_u_height = 8; // U's requested. See actual_panel_height below.

// --- Motherboard (MSI MEG X670E ACE) ---
board_w = 277;    // mm, sourced (MSI/Micro Center) — the IO-edge (width) axis
board_d = 304.8;  // mm, sourced — the depth axis, extended beyond std ATX (EATX)
mount_plate_depth = 12; // mm placeholder, standoff/gusset depth

// Standard ATX 9-hole mounting pattern, sourced from Intel ATX Spec 2.01
// Fig. 3 (bitsavers.org), for a 305x244mm board, hole positions in inches
// from the board's top-left corner (X right, Y down):
atx_std_w_in = 12.0;
atx_holes_in = [
    [0.650, 0.400], [5.550, 0.400],                 // A, C
    [11.750, 1.300],                                  // F
    [0.650, 6.500], [5.550, 6.500], [11.750, 6.500], // G, H, J
    [0.650, 7.950], [5.550, 7.950], [10.950, 7.950]  // K, L, M
];
// ADAPTED for this board: X scaled by board_w/standard_width (277/305mm) since
// the board is narrower than standard ATX and 3 of the 9 holes would fall off
// the edge unscaled. Y is left unscaled — EATX boards conventionally keep the
// standard hole positions near the IO edge and add extra length below, rather
// than stretching everything proportionally. NOT VERIFIED against MSI's actual
// drawing — cross-check against the existing acrylic plate before drilling.
mobo_hole_scale_x = board_w / (atx_std_w_in * 25.4);
mobo_hole_d = 3.2; // mm, clearance-ish; cut as small slots for tolerance, not tight holes

// --- IO shield cutout (standard ATX/EATX size — sourced, genuinely universal) ---
// Standard, UNROTATED orientation: io_w (158.75mm) runs left-right, io_h
// (44.45mm) is the cut's height. Confirmed against a close crop of
// docs/photos/rack-front.jpg this round — the visible port layout (USB
// grid in 2 rows, WiFi antennas side by side, audio jacks in a row) is
// the MSI ACE's completely standard rear IO panel, not a rotated one.
io_w = 158.75;
io_h = 44.45;
io_margin = 8; // mm, margin around the cutout within its own column — placeholder

// --- PSU (Corsair RM850e — real ATX PSU mechanical spec, sourced) ---
psu_w = 150; // mm, sourced, fixed ATX standard
psu_h = 86;  // mm, sourced, fixed ATX standard
psu_d = 140; // mm — ESTIMATE, verify against your RM850e
psu_margin = 3;
// Real 4-hole ATX PSU mounting pattern, sourced from Intel ATX Spec 2.01 Fig. 9,
// origin = bottom-left of the 150x86mm rear face (X right, Y up):
psu_holes = [
    [6.0, 16.0],   // bottom-left
    [6.0, 80.0],   // top-left
    [144.0, 74.0], // top-right
    [120.0, 6.0]   // bottom-right
];
psu_hole_d = 4.0; // mm, clearance for 6-32 screws

// --- GPU cutouts (RTX 5080 Gaming Trio — SOURCED for the 5080 only; the 4070 Ti
// was never looked up separately, these numbers are a placeholder for it too) ---
gpu_card_length    = 338;
gpu_card_height    = 140;
gpu_card_thickness = 50;
gpu_margin = 3;
slot_pitch = 20.32; // mm, sourced — Protocase ATX/PCI enclosure design guide
                     // (Fig. 9, "PCI position pitch"), confirms this figure
gpu_bracket_hole_d = 3.5; // mm, clearance for a 6-32 screw. Protocase's spec
                           // gives 2.71mm (0.1065in) as the TAP drill for
                           // cutting 6-32 threads directly into sheet metal —
                           // sized up here for a clearance hole through
                           // printed plastic (screw + nut or heat-set insert)
                           // rather than tapping the plastic itself.
gpu_shelf_depth = gpu_card_thickness + 2*gpu_margin; // real support ledge —
                           // the card rests on this, not just on a screw

// --- Derived heights ---
psu_seg_height = psu_h + 2*psu_margin;
io_bezel_height = io_h + 2*io_margin;
top_row_height = max(psu_seg_height, io_bezel_height);
gpu_row_height = gpu_card_height + 2*gpu_margin;
requested_panel_height = tray_u_height * u_pitch;
required_panel_height  = top_row_height + gpu_row_height;
actual_panel_height = max(requested_panel_height, required_panel_height);

// --- Derived widths — each column sized to what it actually has to hold,
// not an assumed 50/50 split (that split fit neither the PSU nor the IO
// shield; see the header note). ---
spine_width = 10;
psu_col_w = psu_w + 2*psu_margin;      // 156mm — PSU's own real width + margin
io_col_w  = io_w + 2*io_margin;        // 174.75mm — IO shield's own real width + margin
required_tray_width = psu_col_w + spine_width + io_col_w;
tray_width = max(rack_clear_width, required_tray_width);
spine_x = psu_col_w; // shared by the top row and the GPU row below it
right_col_w = tray_width - spine_width - psu_col_w; // == io_col_w unless rack_clear_width > required

// --- Structure ---
plate_t = 6;
wall_t  = 4;
ear_t   = 4;

// --- Slide hardware ---
slide_hole_pitch  = 32;   // PLACEHOLDER — verify against your slides
slide_tab_height  = 20;
slide_tab_screw_d = 5;

$fn = 48;

// ============ derived ============
tray_depth = rack_overall_d;
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

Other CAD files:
cad/tray-v1/base.stl
cad/tray-v1/board_frame.stl
cad/tray-v1/faceplate.stl
cad/tray-v1/left_wall.stl
cad/tray-v1/psu_shelf.stl

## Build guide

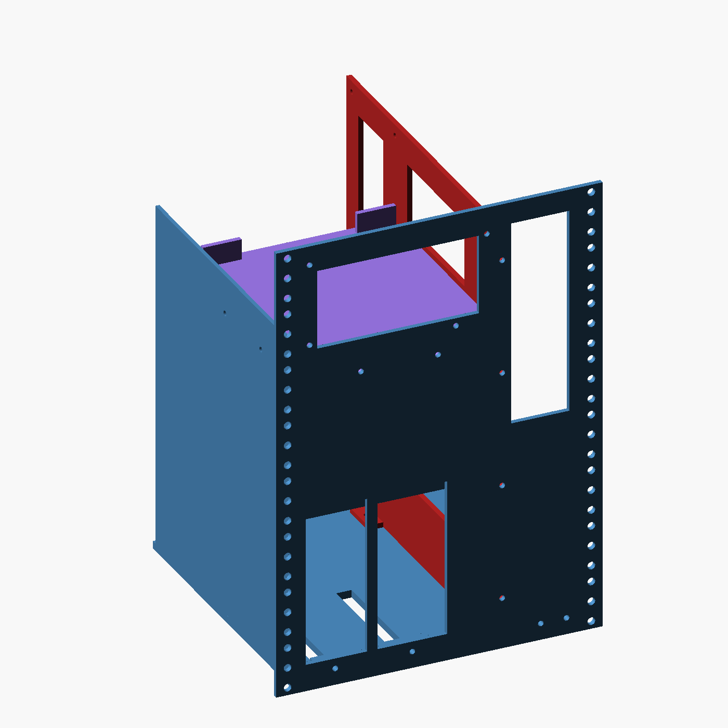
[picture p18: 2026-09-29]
cad/tray-v1/views/iso_printed.png

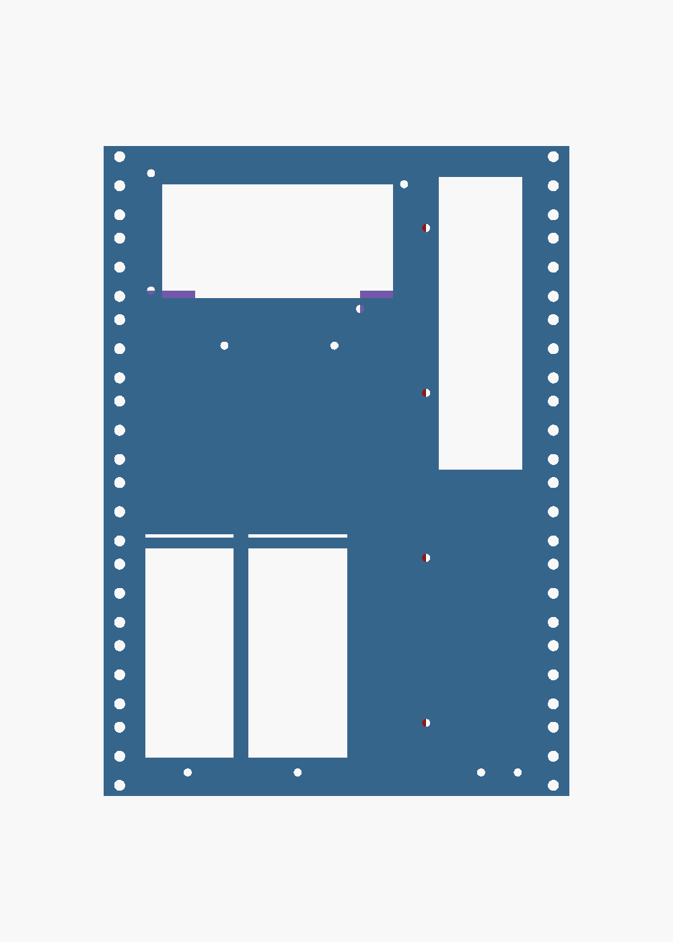
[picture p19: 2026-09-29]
cad/tray-v1/views/front_printed.png

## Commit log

2026-09-26 chore: initial scaffold for mini-rack-cluster
    Documents the physical consolidation of nova-linux, machub, and
    spark-a81e plus network gear into a 10" rack: parts list, paid vs
    current market pricing, build notes, and a LinkedIn post draft.
    Network configs are kept abstracted (port maps only) — no raw device
    exports, serials, MACs, or internal topology in this public repo.
    Claude-Session: https://claude.ai/code/session_01Pb5nzfNVd2MW8Zda4ycyEF
2026-09-26 docs: add rack build photo
    Stripped all EXIF/GPS metadata before committing (re-encoded through
    PIL, verified clean — no exif tags, no location data, no device
    make/model).
    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
2026-09-26 feat: draft parametric CAD for slide-out mobo/GPU/PSU tray
    v0.1 OpenSCAD model: EATX motherboard mounting zone offset from the
    right edge, vertical GPU bracket fin in the remaining strip, PSU
    cradle, front EIA-310 rack ears, and mounting tabs for off-the-shelf
    drawer slides (not printed rails — plastic can't reliably carry
    mobo + 2 GPUs + PSU through repeated slide cycles).
    Not print-ready. Sourced dimensions (board size, EIA-310 standard,
    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
    [mobo-gpu-psu-tray.scad, mobo-gpu-psu-tray.stl]
2026-09-26 feat: v0.2 tray — vertical mobo mount, IO cutout, 8U, color-coded parts
    Switched the motherboard mount from flat/horizontal to vertical.
    v0.1 laid the board flat on the tray floor; that breaks once the IO
    shield needs to be front-facing, since a flat-mounted board's ports
    project sideways at deck height. Vertical mounting also matches how
    the current acrylic-plate build already works — the mounting plate
    now doubles as the front IO bezel.
    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
    [mobo-gpu-psu-tray.scad, mobo-gpu-psu-tray.stl, part-gpu.stl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]
2026-09-26 feat: v0.3 tray — rear-panel layout (mobo/PSU/GPU segments + flanges)
    Rebuilt around what this front face actually is: a standard PC case
    rear panel (IO shield + PSU cutout + expansion-slot brackets), facing
    the rack's front instead of a desk's back. Replaces v0.2's floor-plan
    approach with four tiled segments matching the described layout:
    - PSU (purple): top-right, real ATX cutout (150x86mm) + support shelf
    - GPU (green): below the PSU, 2 stacked cutouts sized from the RTX
    5080 Gaming Trio's real dimensions (338x140x50mm) -- the 4070 Ti
    was never looked up separately, same numbers reused as a flagged
    placeholder
    - Motherboard (red): left column, IO cutout, unpunched standoff zone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
    [mobo-gpu-psu-tray.scad, mobo-gpu-psu-tray.stl, part-gpu.stl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]
2026-09-26 feat: v0.4 tray — corrected layout, real mounting holes, rack reference
    Corrected the layout against the actual build photo
    (docs/photos/rack-front.jpg) after v0.3 guessed wrong: PSU is top-left
    in the real build, not top-right, and everything mounts via open
    brackets/shelves with components' own faces exposed directly (no
    blanking panels like a finished case -- that was the wrong paradigm).
    - PSU (purple): top-left, open bracket, real 4-hole ATX screw pattern
    (Intel ATX Spec 2.01 Fig. 9 -- genuinely universal, high confidence)
    - Motherboard (red): top-right IO bezel + full-board-width standoff
    plate set back in depth. Real 9-hole ATX pattern (Fig. 3) adapted
    (X scaled 277/305, Y un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
    [mobo-gpu-psu-tray.scad, mobo-gpu-psu-tray.stl, part-gpu.stl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]
2026-09-28 fix: v0.5 tray — rotate IO cutout, bond rack flanges, add real GPU mount
    v0.4 shipped with three defects, caught by re-rendering and looking
    instead of trusting the code:
    - IO cutout was cut in desktop-case orientation (158.75mm wide) and
    didn't even fit its own 130mm bezel column. The photo shows the
    ports stacked vertically, not side by side — rotated the cutout 90deg
    and gave the bezel its own column height.
    - rack_ear() touched the base plate along a single zero-area edge, not
    a real bonded joint. Rebuilt as an L-bracket with a foot that
    overlaps the tray's full height. Also fixed the fit_check render
    sitting 33mm below the rack's real first U, which made the flanges
    l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
    [mobo-gpu-psu-tray.scad, mobo-gpu-psu-tray.stl, part-gpu.stl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]
2026-09-28 fix: v0.6 tray — revert wrong IO rotation, rebuild floorplan from real sizes
    Called out for shipping v0.5 still broken; re-examined instead of
    patching again:
    - v0.5's 90deg IO rotation was based on misreading the photo. A zoomed
    crop shows a completely standard MSI X670E ACE rear IO panel (2-row
    USB grid, side-by-side antennas) — not a rotated shield. Reverted.
    The v0.5 fix also only rotated the cutout, not the standoff holes on
    the same rigid board — inconsistent even if the rotation had been real.
    - Independently, checking every cutout against its own panel bounds
    (previously never done — only glanced at renders) found the PSU
    cutout (150mm) was being cut from a 130mm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
    [mobo-gpu-psu-tray.scad, mobo-gpu-psu-tray.stl, part-gpu.stl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]
2026-09-29 feat: rebuild the slide-out tray from zero (v1.0), audited
    Scrap the OpenSCAD v0.1-0.6 design, which modelled the motherboard as a
    plate facing the front. Measured from the photo instead: the IO strip is
    ~59 x 152 mm next to a 150 x 86 mm PSU face, so the board stands edge-on
    like in a PC tower with its IO edge to the front.
    New design lives in asset-forge/3d-design (build123d + a fail-closed mesh
    audit); cad/tray-v1 holds the outputs: 8U 10-inch faceplate with corrected
    EIA-310 holes, PSU shelf, board frame with the ten ATX standoff holes read
    from the drawing, base, side wall. 280 audit checks pass and nine builder
    sabotages are each caught. Open items (rack opening, slides, PSU depth and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
    [base.step, base.stl, board_frame.step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]
